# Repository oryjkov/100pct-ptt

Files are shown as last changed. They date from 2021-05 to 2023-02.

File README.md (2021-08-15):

# 100pct-ptt a.k.a. Clickoris

A BLE hardware button for transmitting over the [Zello](http://zello.com) push-to-talk app while flying a
paraglider.

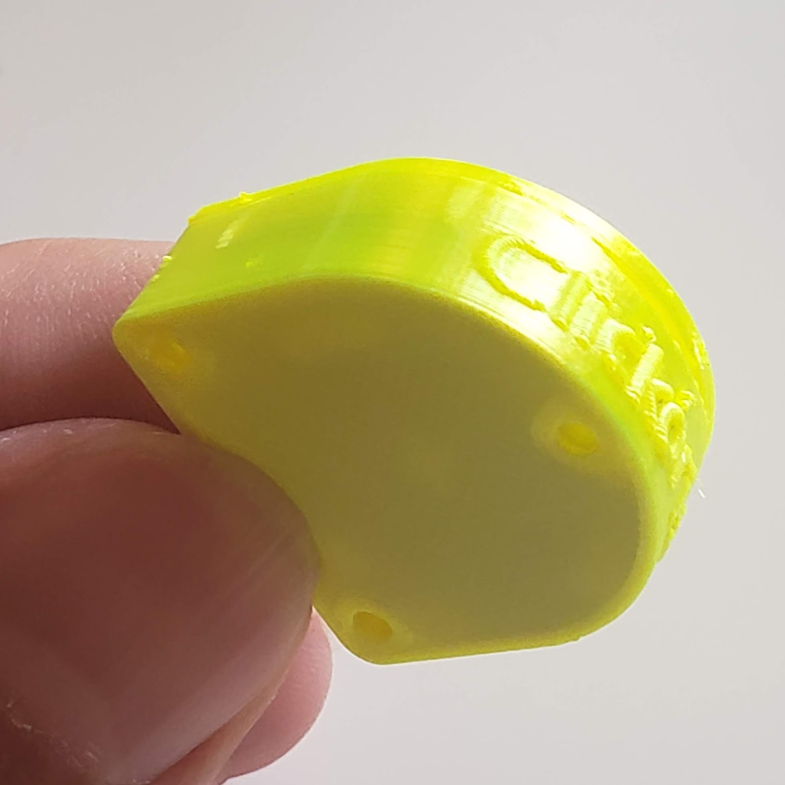
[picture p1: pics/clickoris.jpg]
Clickoris
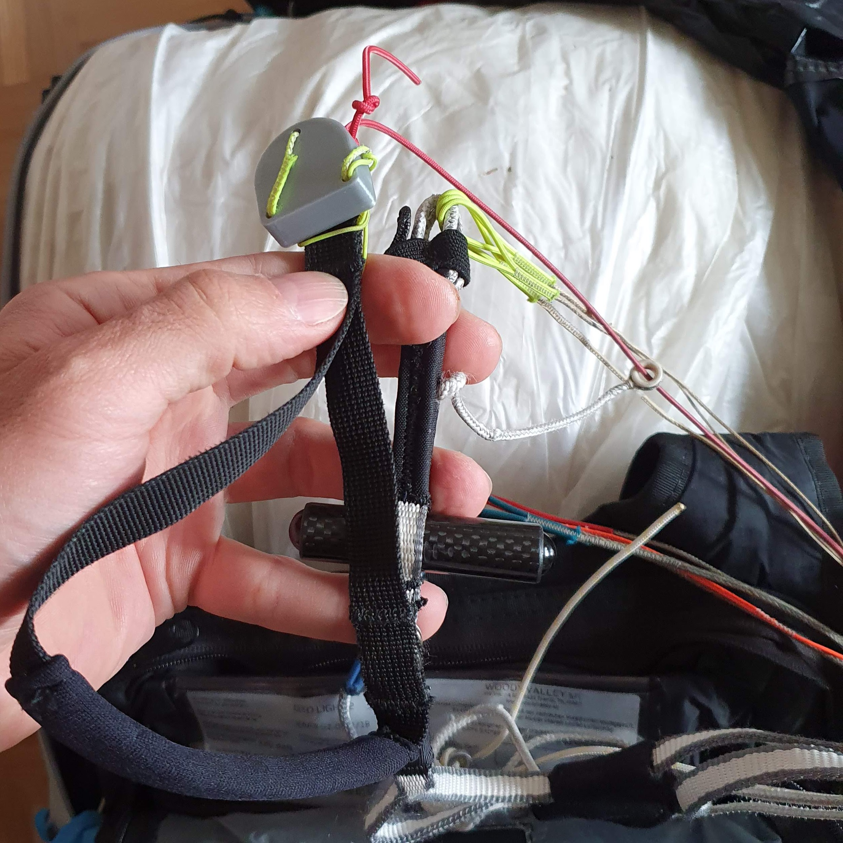
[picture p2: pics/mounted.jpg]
Mounted on a break toggle
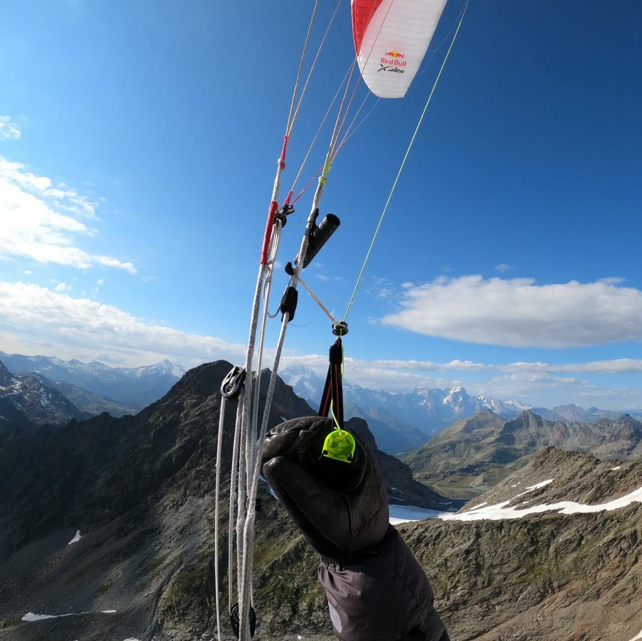
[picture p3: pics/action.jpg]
In action
||||
|-|-|-|

* [Introduction](#introduction)
* [How to make one](#how-to-make-one)
* [Programming the board](#programming-the-board)
   * [Pinout diagram](#pinout-diagram)
   * [Flashing](#flashing)
   * [Flashing case](#flashing-case)
* [Printing](#printing)
* [Pairing with Zello](#pairing-with-zello)
* [Code dependencies](#code-dependencies)
* [TODOs](#todos)

## Introduction

Clickoris was created to help communicating with others during cross-country flights.
It improves on handheld UHF radios when flying in an area with good cellular network
coverage (Swiss Alps).

The device is based on an [nrf51822](https://www.nordicsemi.com/products/nrf51822) BLE beacon
([aliexpress](https://www.aliexpress.com/item/32810276263.html)), powered by a CR2032 battery.
It integrates with the Zello App (Android and iPhone).

The provided 3D-printed case is designed to be mounted to a brake toggle, keeping the device within easy reach
and making it possible to push the button even when wearing thick gloves.

Once paired in the Zello app, button stays connected for several hours and can be used even
with the phone screen turned off or when running another app. When not in use, the button is powered
off (a click powers it on). When powered off, battery usage is close to zero, and the button
should remain usable for several years.

## How to make one

1. Get the parts (use the provided links to AliExpress)

    |[board](https://www.aliexpress.com/wholesale?SearchText=NRF51822+beacon)|[programmer](https://www.aliexpress.com/wholesale?SearchText=stlink+v2)|CR2032 battery|
    |:-:|:-:|:-:|
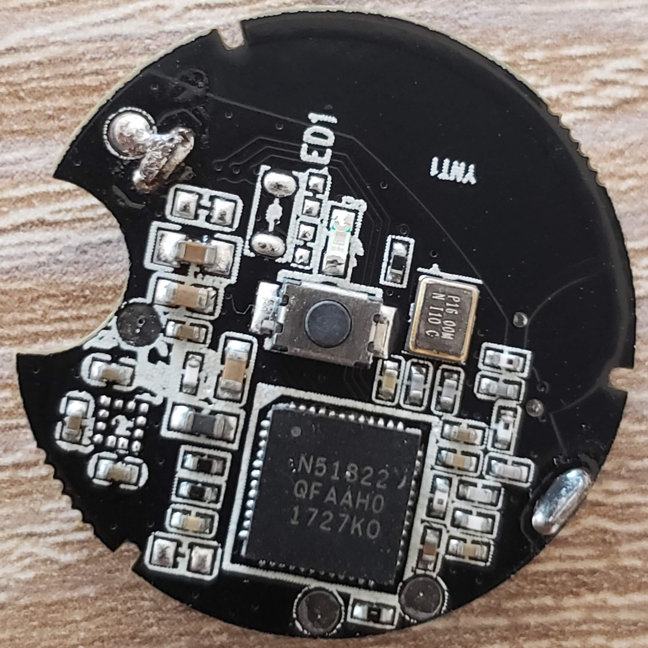
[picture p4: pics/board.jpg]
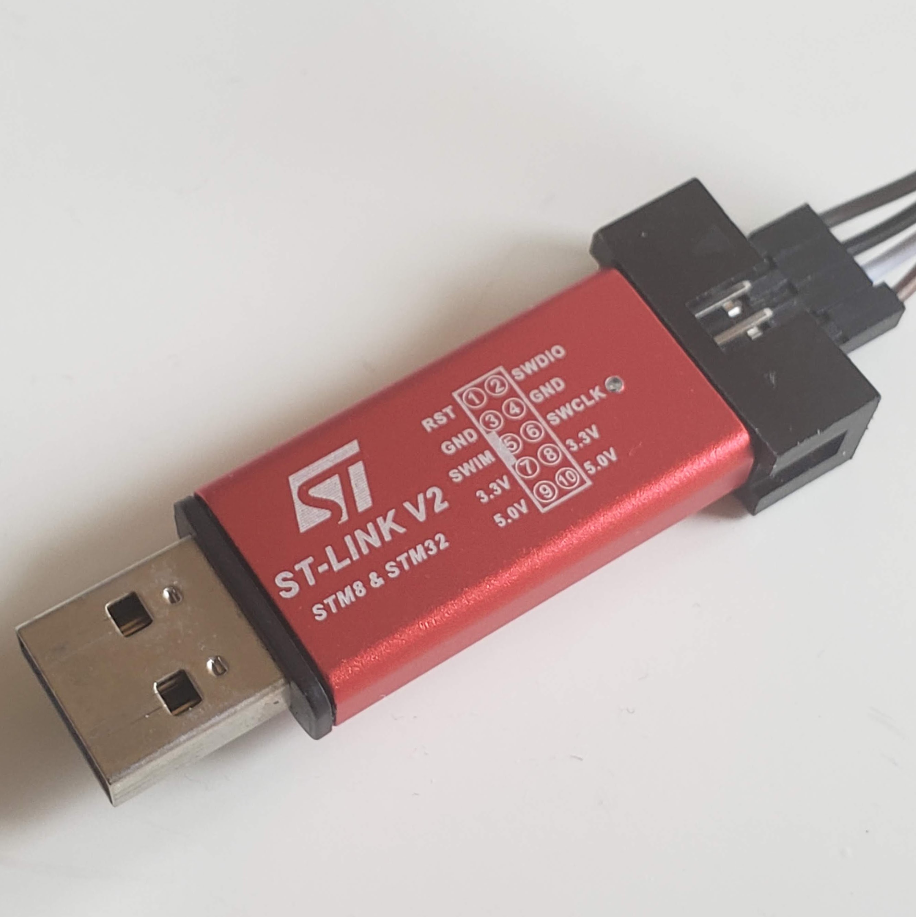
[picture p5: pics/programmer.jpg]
    ||||

1. [Program](#programming-the-board) the board.

1. Print the case, it consists of 2 parts:
    - base `bleButtonCase/baseCase.stl`
    - cover `bleButtonCase/cap.stl`

1. [Pair](#pairing-with-zello) with Zello.

1. Tie it to a brake handle.

1. Go fly.

## Programming the board

The board is programmed with an STLink V2 programmer using 4 pins (SWDIO, SWCLK, GND, 3.3V). It
is possible to simply solder the 4 wires to the board (pinout below), or build a [flashing case](#flashing-case).

### Pinout diagram 
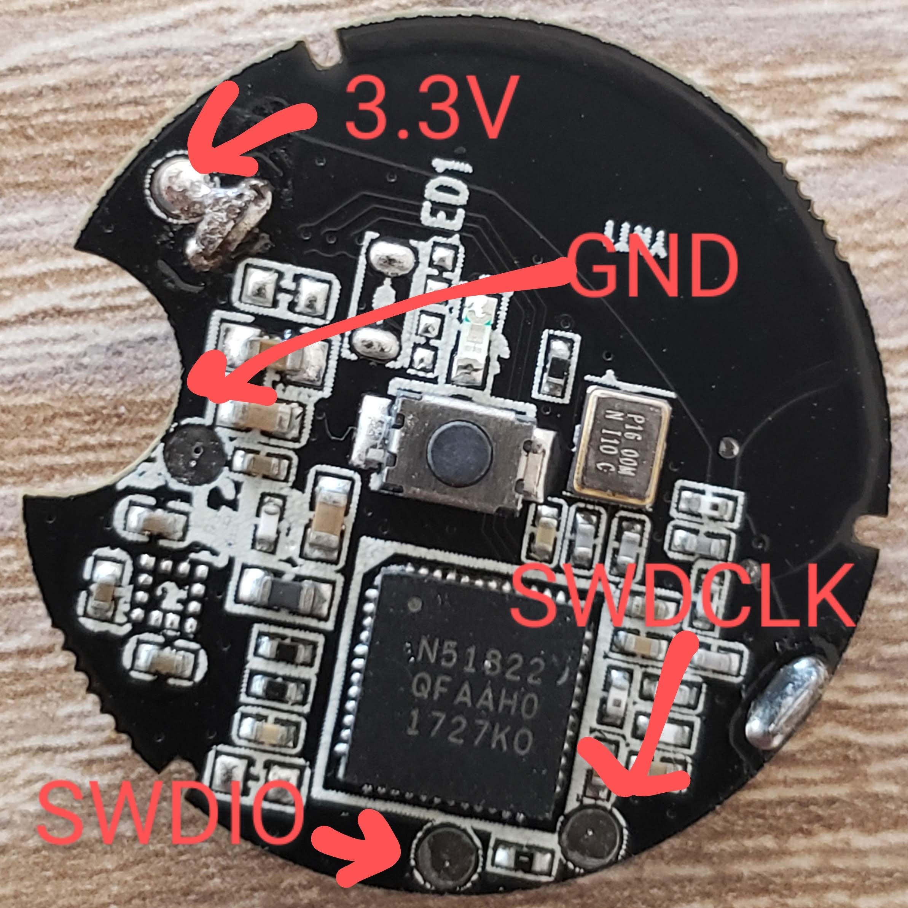
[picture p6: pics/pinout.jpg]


### Flashing

Flashing is done from the [PlatformIO VSCode plugin](https://platformio.org/). Install it first and open this repository in PlatformIO.

Before programming the button, it is necessary to apply a patch to the BLE stack of the Arduino
framework, otherwise the power usage will be significantly higher. The patch is located
in `src/lowPow.patch` and more information is available in this [blog post](https://www.iot-experiments.com/nrf51822-and-ble400/)

Once the patch is applied, it should be just the matter of uploading the firmware.

To check if the Clickoris is working, install the battery and push the button. It should make the green light blink once quickly.
If the light stays off, read on.

**NOTE** in in some cases the button did not work after flashing from PlatformIO. In those cases it
helped to:
1. [Flash the NRF softdevice](https://github.com/sandeepmistry/arduino-nRF5#flashing-a-softdevice) from the Arduino IDE.
1. Program it from PlatformIO as normal(see [TODOs](#todos)).

### Flashing case

To make programming many buttons easier it is worth building a special case to avoid having to solder the programming wires.

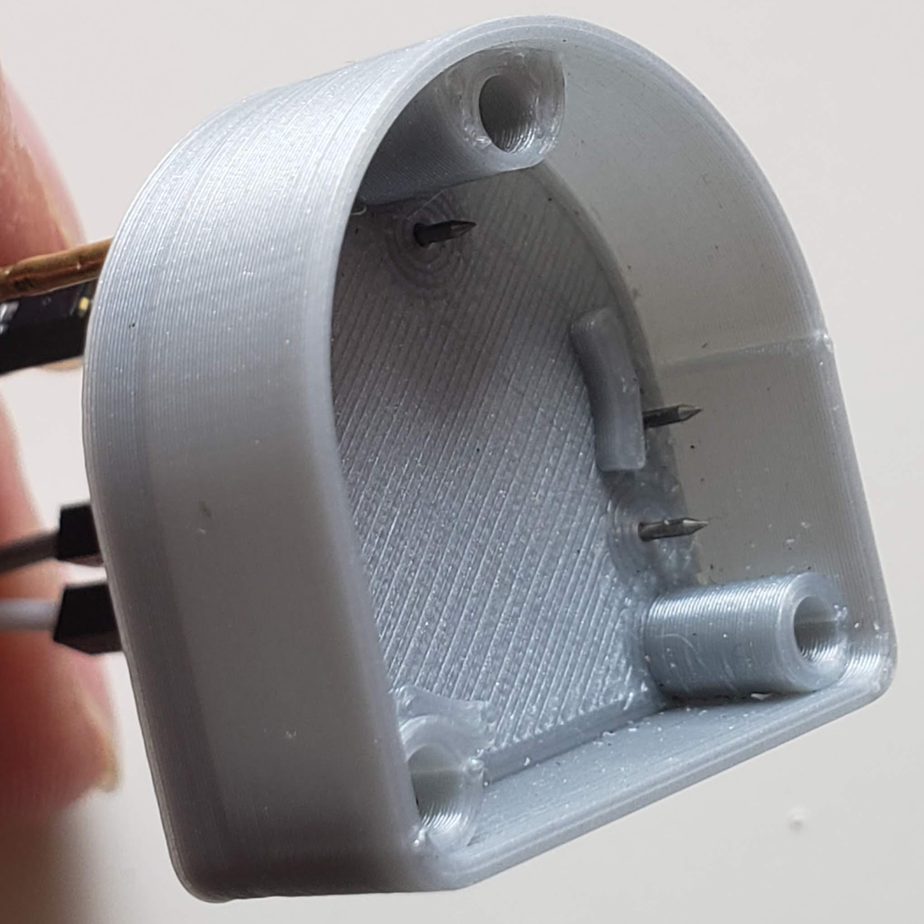
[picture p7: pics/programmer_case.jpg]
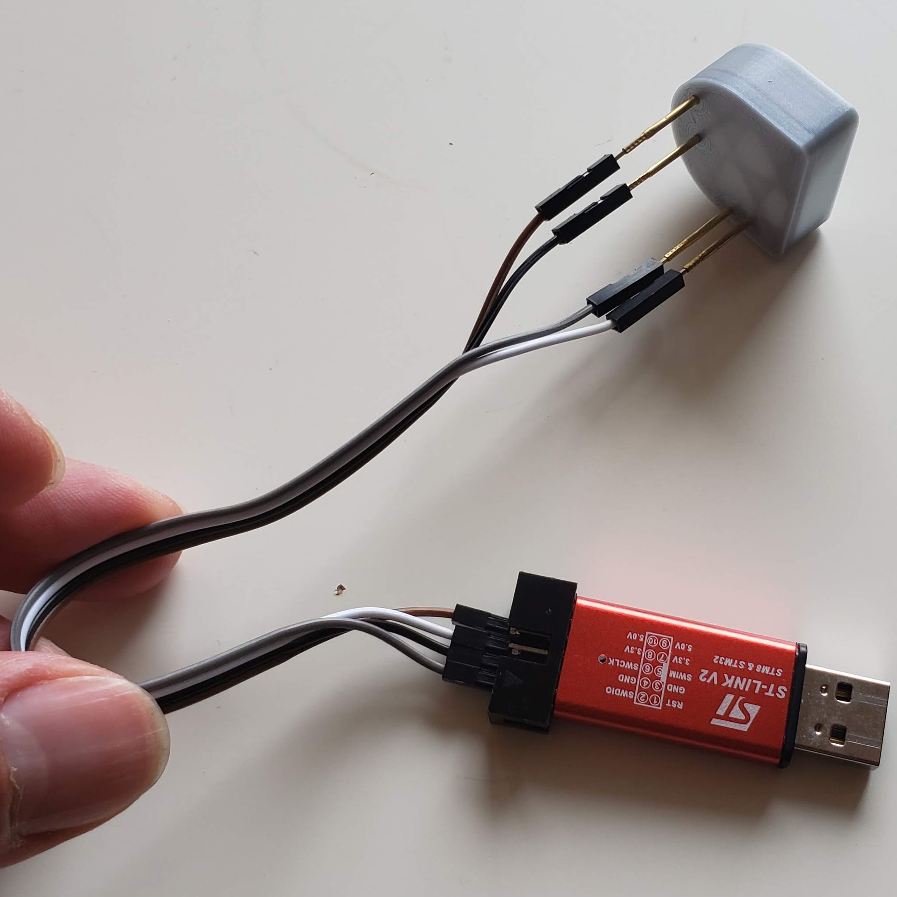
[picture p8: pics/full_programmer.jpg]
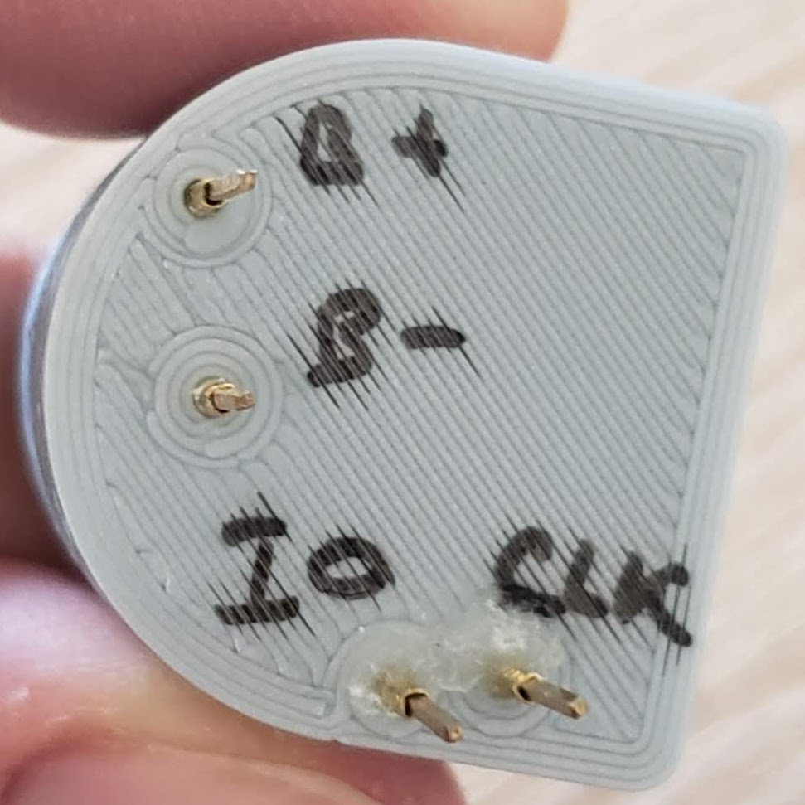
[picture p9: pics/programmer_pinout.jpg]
||||
|-|-|-|

Four spring-loaded pins are glued to the 3D-printed case so that the board can be pushed in with a finger against the contacts
while it is being flashed.

The pins are connected to an STLink V2 using the following pinout from the image above ("B" stands for battery).

## Printing

Printed with no supports, 15% infill works OK. Use 0.2mm layer height as this is what I've tested with. Both parts of the case
can be printed in one go.

## Pairing with Zello

Android [instructions](https://docs.google.com/document/d/1WHSKjbKlpSfUliMCR7onvabltsctEBkE9Yl1S6ZhOwA/edit). Pairing with an iPhone should be similar.

## Code dependencies

1. VSCode + PlatformIO with the arduino framework and the NRF S130 softdevice.

1. [BLEPeripheral](https://github.com/sandeepmistry/arduino-BLEPeripheral).
This library is forked here, as a few low-level modifications were needed to get it working with an iPhone. 

## TODOs

- Report battery level to the phone.

The code is already there, but the service is not exported as I haven't tested it with an iphone yet.

- Figure out why sometimes it is necessary to flash the NRF softdevice via [the arduino programmer](https://github.com/sandeepmistry/arduino-nRF5)

In some cases flashing using Platform IO does not work (only happened on some boards), but it started to work
after I flashed the softdevice from the Arduino IDE.

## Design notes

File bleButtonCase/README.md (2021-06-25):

Case for a NRF51288-based BLE button. Used for Zello.

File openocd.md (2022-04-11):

When programming from platformIO
```
-d1 \
-s /home/olegr/.platformio/packages/tool-openocd/scripts \
-f interface/stlink.cfg \
-c "transport select hla_swd; set WORKAREASIZE 0x4000" \
-f target/nrf51.cfg \
-c "program {.pio/build/seeedTinyBLE/firmware.hex} verify reset; shutdown;" \
```

programming from arduino

```
/home/olegr/.arduino15/packages/sandeepmistry/tools/openocd/0.10.0-dev.nrf5/bin/openocd
-d0 -f interface/stlink-v2.cfg -c "transport select hla_swd; set WORKAREASIZE 0x4000;" -f target/nrf51.cfg -c "init; halt; nrf51 mass_erase; program {{/home/olegr/.arduino15/packages/sandeepmistry/hardware/nRF5/0.7.0/cores/nRF5/SDK/components/softdevice/s130/hex/s130_nrf51_2.0.1_softdevice.hex}} verify reset; shutdown;"
```

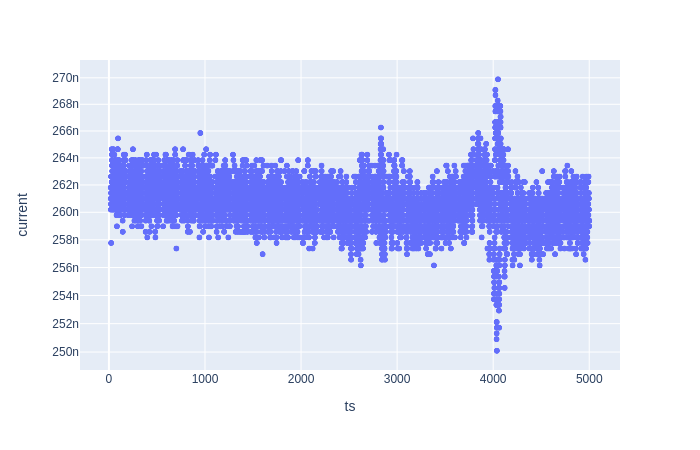
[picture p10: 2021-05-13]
power/system_off.png

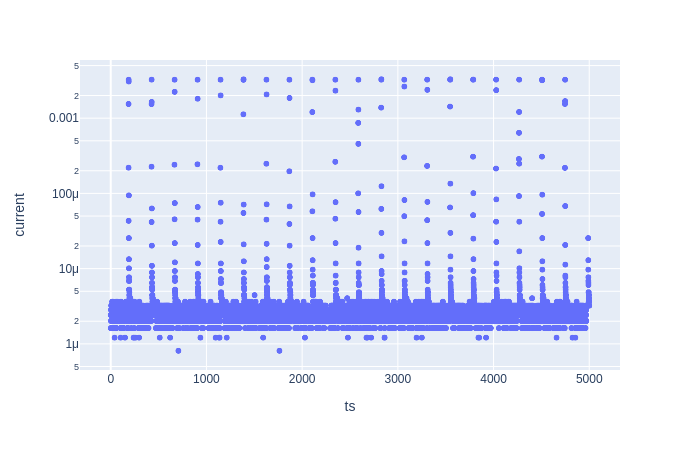
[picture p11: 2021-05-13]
power/connected.png

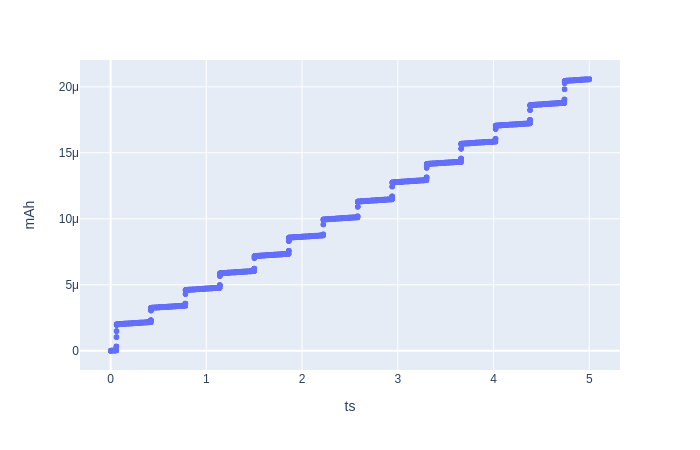
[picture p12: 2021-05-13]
power/conn_300ms_total.png

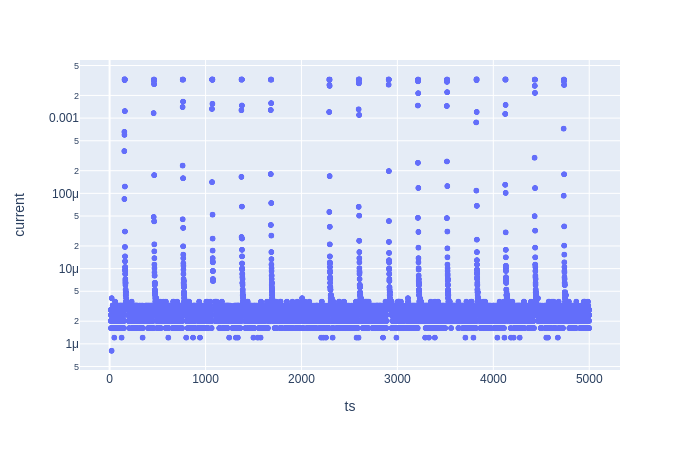
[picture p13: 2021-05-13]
power/advertising_300ms.png

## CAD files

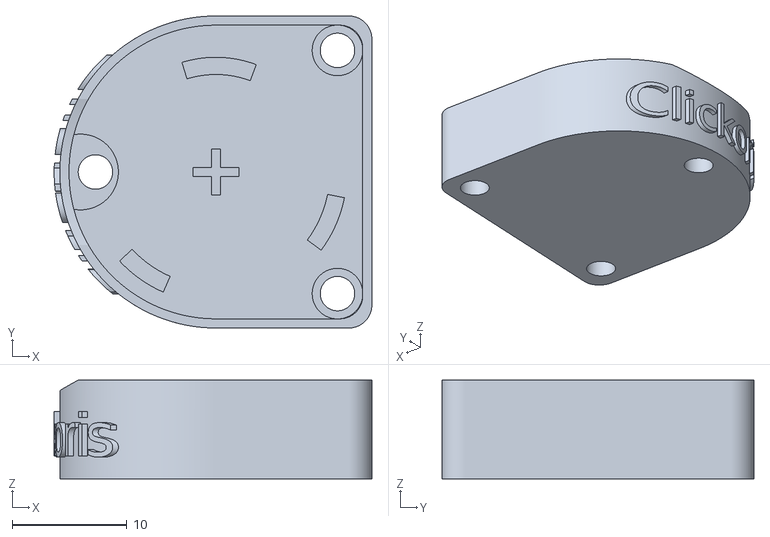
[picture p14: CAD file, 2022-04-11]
bleButtonCase/baseCaseThick.stl
27.7 x 27.2 x 8.60

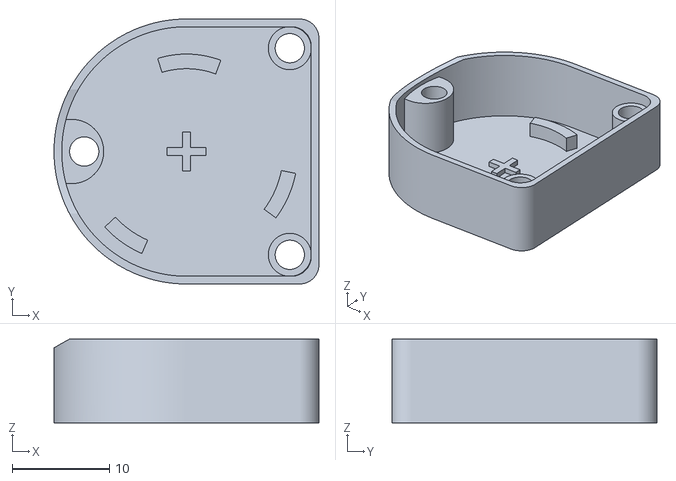
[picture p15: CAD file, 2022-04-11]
bleButtonCase/baseCase.stl
27.2 x 27.2 x 8.60

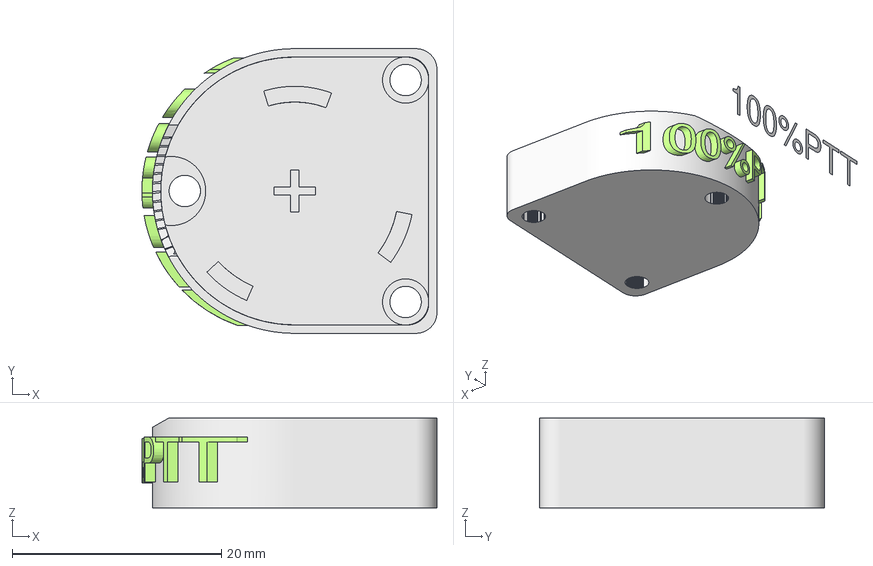
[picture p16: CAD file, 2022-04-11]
bleButtonCase/bleButtonCaseTriangle.FCStd
36.6 x 27.2 x 8.60 mm
Cap
ShapeString
Projection Object
Cap (Meshed)

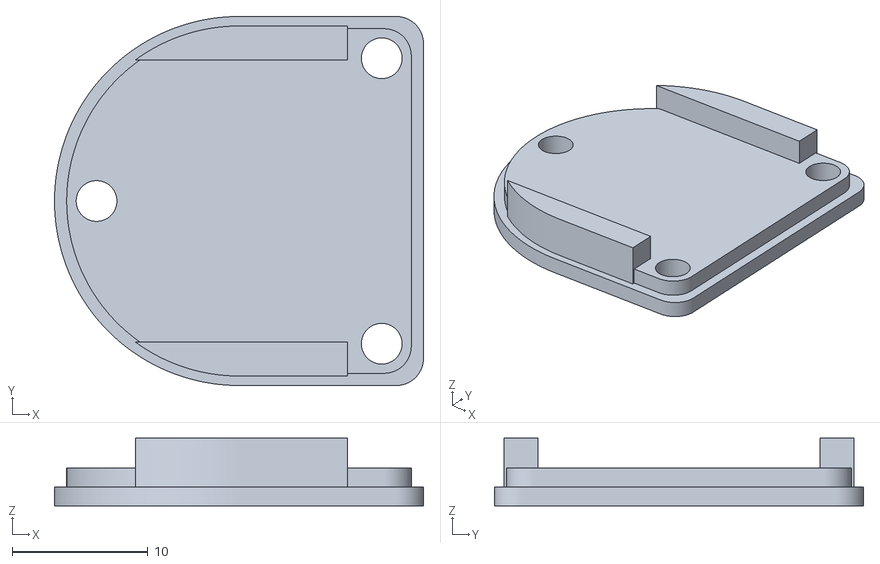
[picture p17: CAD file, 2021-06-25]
bleButtonCase/cap.stl
27.2 x 27.2 x 5.00

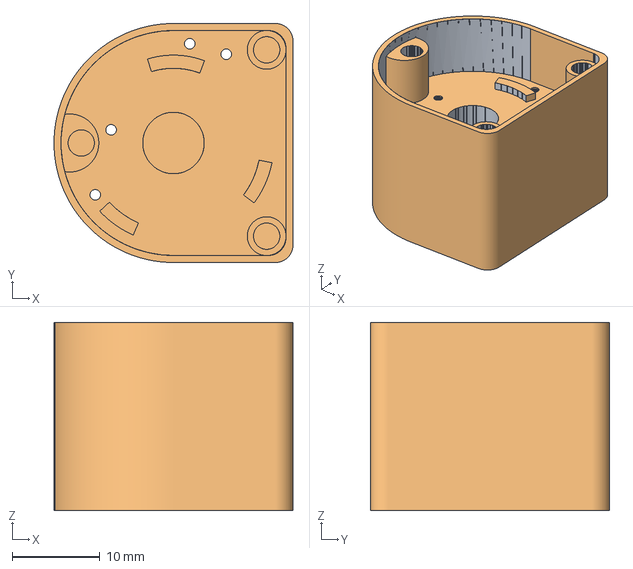
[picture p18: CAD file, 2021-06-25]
bleButtonCase/bleButtonProgrammer.FCStd
27.2 x 27.2 x 21.4 mm
Cut (Meshed)

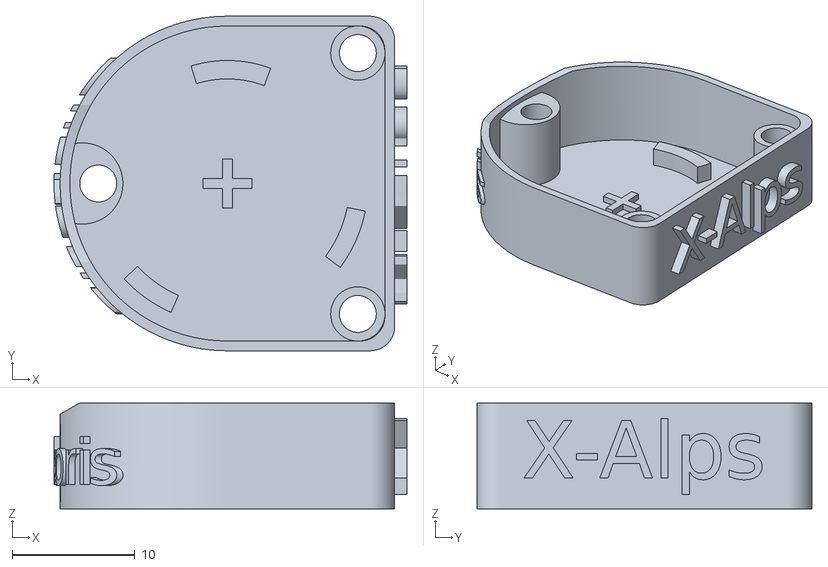
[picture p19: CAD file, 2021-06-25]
bleButtonCase/xalpsCase.stl
28.7 x 27.2 x 8.60

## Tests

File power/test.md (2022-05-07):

Power consumption values of the BT button in the various states.

system off:
Total: 7.130696e-07 mAh (over 10.0 sec), per hour: 2.567030e-04 mAh, est. battery life: 818066.0 (hours)

advertising (1s):
Total: 4.796562e-05 mAh (over 10.0 sec), per hour: 1.726691e-02 mAh, est. battery life: 12162.0 (hours)
advertising (100ms):
Total: 1.912123e-03 mAh (over 60.0 sec), per hour: 1.147272e-01 mAh, est. battery life: 1830.4 (hours

bonded (100ms):
Total: 1.104320e-04 mAh (over 10.0 sec), per hour: 3.975401e-02 mAh, est. battery life: 5282.5 (hours)

transmitting:
Total: 1.196119e-02 mAh (over 10.0 sec), per hour: 4.305997e+00 mAh, est. battery life: 48.8 (hours)

## Test on 06.05.2022
Ran for 2 hours without the phone being around.

In the first 500 sec est battery life was 8000 hours. (sleep mode)

### Original PTTZ button
connected running for 1 minute: 16000 hours lifetime.
On but not connected for 1 minute: 1400 hours lifetime.
Connected and button pressed for 1 minute: 380 hours lifetime.

My button (similar setup)
connected: 5700 hours
On but not connected: 750000 hours
Transmitting: 50 hours

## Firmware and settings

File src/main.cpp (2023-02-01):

#include <BLEPeripheral.h>

#include "blink.h"
#include "nrf_nvic.h"
#include "pins.h"
#include "types.h"

// How long to wait after the last button press before shutting down the system
// from the connected state.
static const uint32_t kDisconnectAndShutdownDelayMs = 6 * 60 * 60 * 1000;
// for xalps buttons:
//static const uint32_t kDisconnectAndShutdownDelayMs = 300 * 60 * 60 * 1000;
// How long to wait after the last button press before shutting down the system
// from the advertising state.
static const uint32_t kShutdownDelayMs = 1 * 60 * 1000;

// Frequency of BT advertising transmissions.
static const uint32_t kAdvertisingIntervalMs = 60;
// min, max connection interval in 1.25ms units. Lower values make the button more responsive.
static const uint32_t kConnectionIntervalMin = 36;  // 45ms
static const uint32_t kConnectionIntervalMax = 36;

volatile bool buttonPressFlag = false;
void buttonInterruptHandler() { buttonPressFlag = true; }

// Used for reading battery voltage. Taken from
// https://os.mbed.com/users/MarceloSalazar/notebook/measuring-battery-voltage-with-nordic-nrf51x/
uint16_t readVoltageAdc(void) {
  NRF_ADC->ENABLE = ADC_ENABLE_ENABLE_Enabled;
  NRF_ADC->CONFIG =
      (ADC_CONFIG_RES_10bit << ADC_CONFIG_RES_Pos) |
      (ADC_CONFIG_INPSEL_SupplyOneThirdPrescaling << ADC_CONFIG_INPSEL_Pos) |
      (ADC_CONFIG_REFSEL_VBG << ADC_CONFIG_REFSEL_Pos) |
      (ADC_CONFIG_PSEL_Disabled << ADC_CONFIG_PSEL_Pos) |
      (ADC_CONFIG_EXTREFSEL_None << ADC_CONFIG_EXTREFSEL_Pos);

  NRF_ADC->CONFIG &= ~ADC_CONFIG_PSEL_Msk;
  NRF_ADC->CONFIG |= ADC_CONFIG_PSEL_Disabled << ADC_CONFIG_PSEL_Pos;
  NRF_ADC->TASKS_START = 1;
  while (((NRF_ADC->BUSY & ADC_BUSY_BUSY_Msk) >> ADC_BUSY_BUSY_Pos) ==
         ADC_BUSY_BUSY_Busy) {
  };
  uint16_t result = static_cast<uint16_t>(NRF_ADC->RESULT);  // 10 bit
  NRF_ADC->ENABLE = ADC_ENABLE_ENABLE_Disabled;
  return result;
}

uint8_t getBatLevel() {
    float volts = readVoltageAdc() * 3.6f / 1024.0f;

    // https://uncannier.com/cr2032-lithium-battery-charge-level-measurement/
    const struct Point { float v; uint16_t c; } vcPairs[] = { 
        {3.0, 100}, {2.9, 80}, {2.8, 60}, {2.7, 40}, 
        {2.6, 30}, {2.5, 20}, {2.4, 10}, {2.0, 0} 
    };

    if (volts >= vcPairs[0].v) return 100;
    if (volts <= vcPairs[7].v) return 0;

    for (int i = 1; i < 8; i++) {
        if (volts > vcPairs[i].v) {
            const Point &p1 = vcPairs[i-1];
            const Point &p2 = vcPairs[i];
            return round(p1.c + (volts - p1.v) * (p2.c - p1.c)/(p2.v - p1.v));
        }
    }
    return 0;
}

BLEPeripheral blePeripheral = BLEPeripheral();

// ffe0 is what a ptt button that worked on an iphone used
BLEService buttonService("ffe0");
// TODO: not sure what this is for, but it seems to make it work on an iphone.
BLEUnsignedCharCharacteristic iphoneCharacteristic("1525", BLERead | BLEWrite);
BLECharCharacteristic buttonCharacteristic("ffe1", BLERead | BLENotify);

BLEService batteryService("180f");
BLEUnsignedCharCharacteristic batteryLevel("2a19", BLERead | BLENotify);

// State transition and executes exit action for the current state.
// Diagram: https://photos.app.goo.gl/6E5oTZQ78MnhBJMR8
StateEnum stateTransition(StateContainer* sc, Event e) {
  StateEnum newState = STATE_INVALID;
  switch (sc->state) {
    case STATE_OFF:
      if (e & EVENT_BUTTON_DOWN) {
        newState = STATE_BROADCAST;
      } else {
        newState = STATE_OFF;
      }
      break;
    case STATE_BROADCAST:
      if (e & EVENT_CONNECTED) {
        newState = STATE_SLEEP;
      } else if (e & EVENT_MINUTES_10) {
        newState = STATE_OFF;
      } else {
        newState = STATE_BROADCAST;
      }
      break;
    case STATE_SLEEP:
      if (e & EVENT_BUTTON_DOWN) {
        newState = STATE_ENSURE_DOWN;
      } else if (e & EVENT_SHUTDOWN_TIMEOUT) {
        newState = STATE_OFF;
      } else if (e & EVENT_DISCONNECTED) {
        newState = STATE_BROADCAST;
      } else {
        newState = STATE_SLEEP;
      }
      break;
    case STATE_ENSURE_DOWN:
      if (e & EVENT_MILLIS_10) {
        newState = STATE_TRANSMIT;
      } else {
        newState = STATE_SLEEP;
      }
      break;
    case STATE_TRANSMIT:
      if (e & EVENT_BUTTON_UP) {
        newState = STATE_ENSURE_UP;
        digitalWrite(LED_PIN, LOW);
      } else {
        newState = STATE_TRANSMIT;
      }
      break;
    case STATE_ENSURE_UP:
      if (e & EVENT_BUTTON_DOWN) {
        newState = STATE_TRANSMIT;
      } else {
        newState = STATE_SLEEP;
        buttonCharacteristic.setValue(0);
        batteryLevel.setValue(getBatLevel());
      }
      break;
    default:
      blinkToDeath();
  }
  if (sc->state != newState) {
    sc->stateEnteredMs = millis();
  }
  sc->state = newState;
  return newState;
}

StateContainer sc;

Event getEvents(StateContainer* sc) {
  Event e = EVENT_NONE;
  if (buttonPressFlag) {
    buttonPressFlag = false;
    e = static_cast<Event>(e | Event(EVENT_BUTTON_DOWN));
  }
  if (digitalRead(BUTTON_PIN) == HIGH) {
    e = static_cast<Event>(e | Event(EVENT_BUTTON_UP));
  }
  if ((millis() - sc->stateEnteredMs) > kDisconnectAndShutdownDelayMs) {
    e = static_cast<Event>(e | Event(EVENT_SHUTDOWN_TIMEOUT));
  }
  if ((millis() - sc->stateEnteredMs) > kShutdownDelayMs) {
    e = static_cast<Event>(e | Event(EVENT_MINUTES_10));
  }
  if ((millis() - sc->stateEnteredMs) > 10) {
    e = static_cast<Event>(e | Event(EVENT_MILLIS_10));
  }
  if (blePeripheral.connected()) {
    e = static_cast<Event>(e | Event(EVENT_CONNECTED));
  } else {
    e = static_cast<Event>(e | Event(EVENT_DISCONNECTED));
  }

  return e;
}

void loop() {
  blinkQuick();
  Event e = getEvents(&sc);
  StateEnum oldState = sc.state;
  stateTransition(&sc, e);

  // Perform the actions upon entering the (new) state.
  switch (sc.state) {
    case STATE_OFF:
      // Do a Power OFF, this is the last statement executed.
      NRF_POWER->SYSTEMOFF = 1;
    case STATE_BROADCAST:
      // Keep sleeping (system ON) until a connection
      // established.
      sd_app_evt_wait();
      // See
      // https://www.iot-experiments.com/nrf51822-and-ble400/
      sd_nvic_ClearPendingIRQ(SWI2_IRQn);
      break;
    case STATE_SLEEP:
      // Keep sleeping (system ON) until a button is pressed.
      sd_app_evt_wait();
      // See
      // https://www.iot-experiments.com/nrf51822-and-ble400/
      sd_nvic_ClearPendingIRQ(SWI2_IRQn);
      break;
    case STATE_ENSURE_DOWN:
      break;
    case STATE_TRANSMIT:
      if (oldState != sc.state) {
        buttonCharacteristic.setValue(1);
      }
      digitalWrite(LED_PIN, HIGH);
      break;
    case STATE_ENSURE_UP:
      break;
    default:
      blinkToDeath();
      break;
  }

  // Do the BLE things.
  blePeripheral.poll();
}

void setup() {
  pinMode(LED_PIN, OUTPUT);
  pinMode(BUTTON_PIN, INPUT);

  digitalWrite(LED_PIN, HIGH);
  delay(100);
  digitalWrite(LED_PIN, LOW);
  delay(500);
  // Button press signals wake up. See
  // https://github.com/sandeepmistry/arduino-nRF5/issues/243
  NRF_GPIO->PIN_CNF[BUTTON_PIN] &= ~((uint32_t)GPIO_PIN_CNF_SENSE_Msk);
  NRF_GPIO->PIN_CNF[BUTTON_PIN] |=
      ((uint32_t)GPIO_PIN_CNF_SENSE_Low << GPIO_PIN_CNF_SENSE_Pos);
  // Button needs a pull up not to be noisy.
  NRF_GPIO->PIN_CNF[BUTTON_PIN] &= ~((uint32_t)GPIO_PIN_CNF_PULL_Msk);
  NRF_GPIO->PIN_CNF[BUTTON_PIN] |=
      ((uint32_t)GPIO_PIN_CNF_PULL_Pullup << GPIO_PIN_CNF_PULL_Pos);

  // set advertised local name and service UUID
  uint8_t mfg_data[] = {0x59,0,0,0x95};
  blePeripheral.setManufacturerData(mfg_data, 4);
  blePeripheral.setLocalName("CLICK");
  blePeripheral.setDeviceName("CLICK");
  blePeripheral.setAppearance(BLE_APPEARANCE_GENERIC_REMOTE_CONTROL);
  blePeripheral.setAdvertisingInterval(kAdvertisingIntervalMs);
  blePeripheral.setConnectionInterval(kConnectionIntervalMin, kConnectionIntervalMax);

  // add service and characteristic
  blePeripheral.setAdvertisedServiceUuid(buttonService.uuid());
  blePeripheral.addAttribute(buttonService);
  blePeripheral.addAttribute(buttonCharacteristic);
  blePeripheral.addAttribute(iphoneCharacteristic);
  
  blePeripheral.addAttribute(batteryService);
  blePeripheral.addAttribute(batteryLevel);

  // begin initialization
  blePeripheral.begin();
  buttonCharacteristic.setValue(0);
  batteryLevel.setValue(getBatLevel());
  iphoneCharacteristic.setValue(1);

  // enable low power mode and interrupt
  sd_power_mode_set(NRF_POWER_MODE_LOWPWR);
  attachInterruptLowAccuracy(digitalPinToInterrupt(BUTTON_PIN),
   buttonInterruptHandler, FALLING);

  sc.state = STATE_OFF;
}

void blePeripheralConnectHandler(BLECentral& central) {
  iphoneCharacteristic.setValue(1);
}

void blePeripheralDisconnectHandler(BLECentral& central) {}

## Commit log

2021-04-22 Added battery level measurement and a BT char for it.
2021-04-23 Send a single transmit start notification. Otherwise it seems too much for android to handle.
    [ble.ino]
2021-05-13 switched to platformio
2021-05-13 Power consumption measurements.
2021-06-25 added the freecad model + exports
    [bleButtonCaseTriangle-Fusion (Meshed).stl, bleButtonCaseTriangle-Fusion001 (Meshed).stl, bleButtonCaseTriangle.FCStd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]
2021-07-05 Use the low frequency RC oscillator
    some boards do not have the crystal
    there is a marginal increase in power consumption, but only when
    sleeping (should not affect power off state)
2021-07-05 stl with case (no xalps)
    [baseCase.stl, bleButtonCaseTriangle-Fusion (Meshed).stl, bleButtonCaseTriangle-Fusion001 (Meshed).stl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]
2021-07-14 changes to make bleperipheral appear like the ptt button
2021-07-14 changes that made the button appear more like ptt-z and work with Oli's iphone
2021-08-01 board image
2022-04-11 change text on the 3d model
    [baseCase.stl, baseCaseThick.stl, bleButtonCaseTriangle.FCStd]
2022-05-07 comparing power usage with the original button
2023-01-31 Battery service added
